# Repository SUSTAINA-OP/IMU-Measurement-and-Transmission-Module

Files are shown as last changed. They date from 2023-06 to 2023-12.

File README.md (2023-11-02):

<html lang="en">

<head>
    <meta charset="uft-8">
    <meta name="author" content="Masato Kubotera">
    <meta name="description" content="">
</head>

<body>
    <p><strong>This product is currently under development!</strong></p>
    <h1>IMU Measurement and Transmission Module</h1>
        <p>
            This product is a module enabling the <a href="https://github.com/SUSTAINA-OP/ICM-42688-P-Module">SUSTAINA-OP/ICM-42688-P-Module</a> (IMU module) to be connected to a USB or RS-485 I/F through a microcontroller.<br><br>
            The <a href="/firmware">firmware</a> for this product to be written to the microcontroller is a modification of the following library.
            <ul>
                <li><a href="https://github.com/finani/ICM42688">finani/ICM42688</a></li>
            </ul>
            (The firmware of this product currently supports only USB I/F connection.)
        </p>
    <h2>Features Rev. 1</h2>
        <p>
            <table>
                <tr>
                    <th>Top Surface of PCB</th>
                    <th>Bottom Surface of PCB</th>
                    <th>Assembled Electronic Components</th>
                </tr>
                <tr>
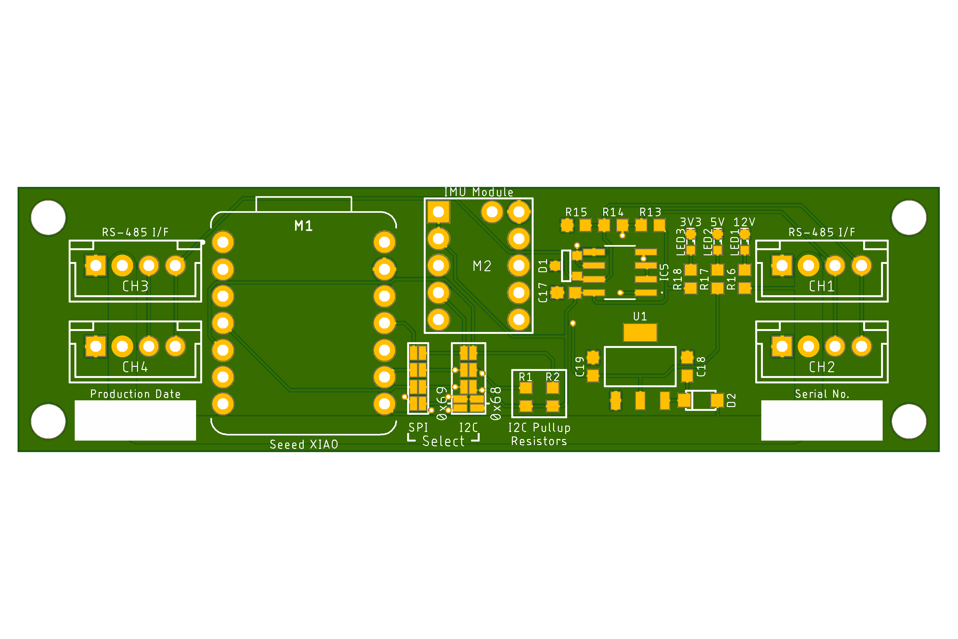
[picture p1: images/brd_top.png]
                    <td></td>
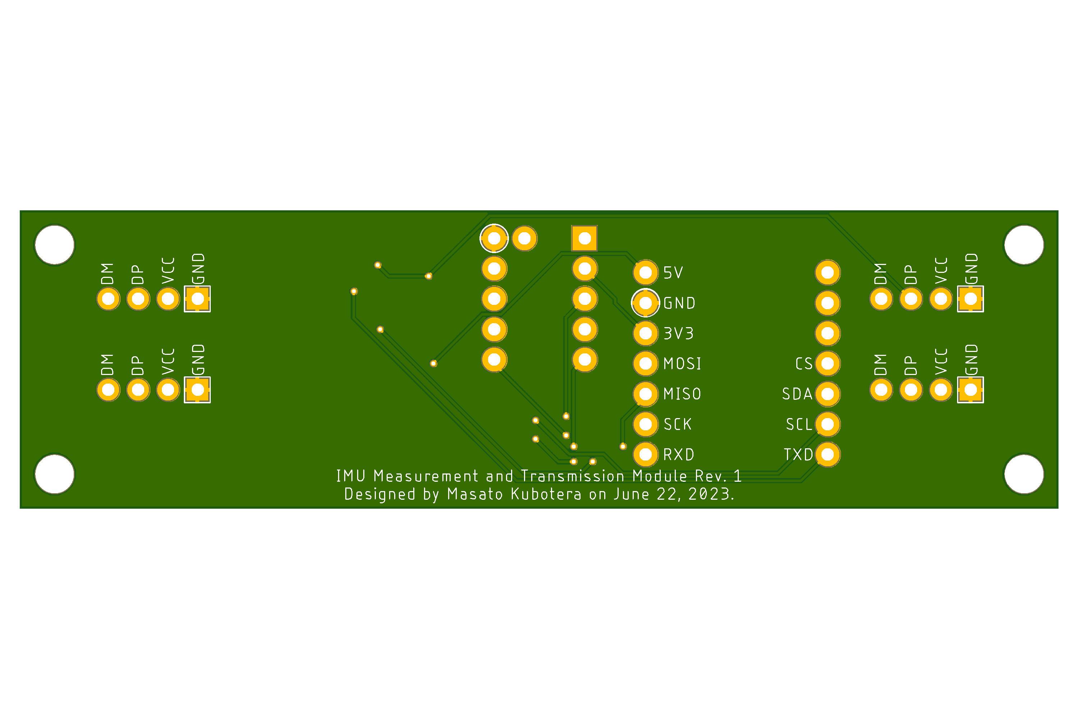
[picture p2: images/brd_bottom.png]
                    <td></td>
                    <td></td>
                </tr>
            </table>
        </p>
    <h3>PCB</h3>
        <p>
            <ul>
                <li>87mm x 25mm PCB layout</li>
            </ul>
        </p>
    <h2>Development Environments</h2>
    <p>
        This product is designed with the following software.
            <ul>
                <li><a href="https://www.autodesk.com/products/eagle/overview">Autodesk Eagle 9.6.2</a></li>
                <li><a href="https://www.arduino.cc/en/software">Arduino IDE 1.8.19</a></li>
            </ul>
    </p>
    <h2>Repository Contents</h2>
        <p>
            <dl>
                <dt><a href="/images">\images</a></dt>
                <dd>PCB preview images and capture of design screen</dd>
                <dt><a href="/libraries">\libraries</a></dt>
                <dd>Libraries used in Autodesk Eagle design</dd>
                <dt><a href="/pcb_order">\pcb_order</a> </dt>
                <dd>Gerber data and documentation for ordering PCB</dd>
                <dt><a href="/firmware">\firmware</a> </dt>
                <dd>Sample firmware to be written to the microcontroller board</dd>
                <dt><a href="/schematic.pdf">schematic.pdf</a></dt>
                <dd>Circuit diagram of this product</dd>
                <dt>*.brd</dt>
                <dd>Board wiring design file by Autodesk Eagle</dd>
                <dt>*.sch</dt>
                <dd>Circuit diagram design file by Autodesk Eagle</dd>
                <dt><a href="/.gitignore">.gitignore</a></dt>
                <dd>A file that tells Git not to track a particular file</dd>
                <dt><a href="/LICENSE">LICENSE</a></dt>
                <dd>License to use this product</dd>
            </dl>
        </p>
    <h2>Documentation</h2>
    <h3>Documentation</h3>
        <p>
            The following design errors have been identified in Rev. 1 of this product.
            <ul>
              <li>TXDEN of UART/RS-485 conversion IC is not wired to the microcontroller board</li>
                When used with USB I/F, there is no problem, but when used with RS-485 I/F, solder a jumper wire between TXDEN and the microcontroller as shown in the figure below.<br>
                
            </ul>
        </p>
    <h2>References</h2>
        
    <h2>Contact</h2>
        <p>
            If you have any questions, please contact the designer of this product, Masato Kubodera, by <a href="mailto:masato.kubotera@sustaina-op.com">e-mail</a>.<br>
            E-mail: <a href="mailto:masato.kubotera@sustaina-op.com">masato.kubotera@sustaina-op.com</a>
        </p>
    <h2>License Information</h2>
        <p>
            This product is open source. Please review the <a href="/LICENSE">LICENSE</a> for license information.<br>
            <br>
            This product by Masato Kubotera is licensed under a <a href="http://creativecommons.org/licenses/by-nc-sa/4.0/">Creative Commons Attribution-NonCommercial-ShareAlike 4.0 International License</a>.
        </p>
</body>
</html>

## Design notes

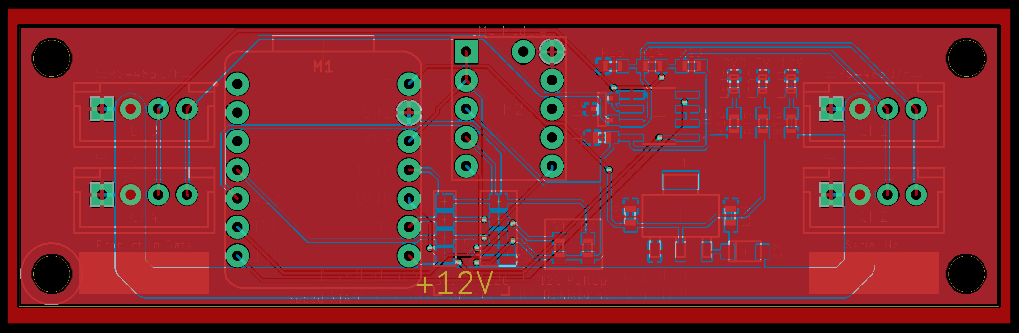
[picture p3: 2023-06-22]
images/brd.png

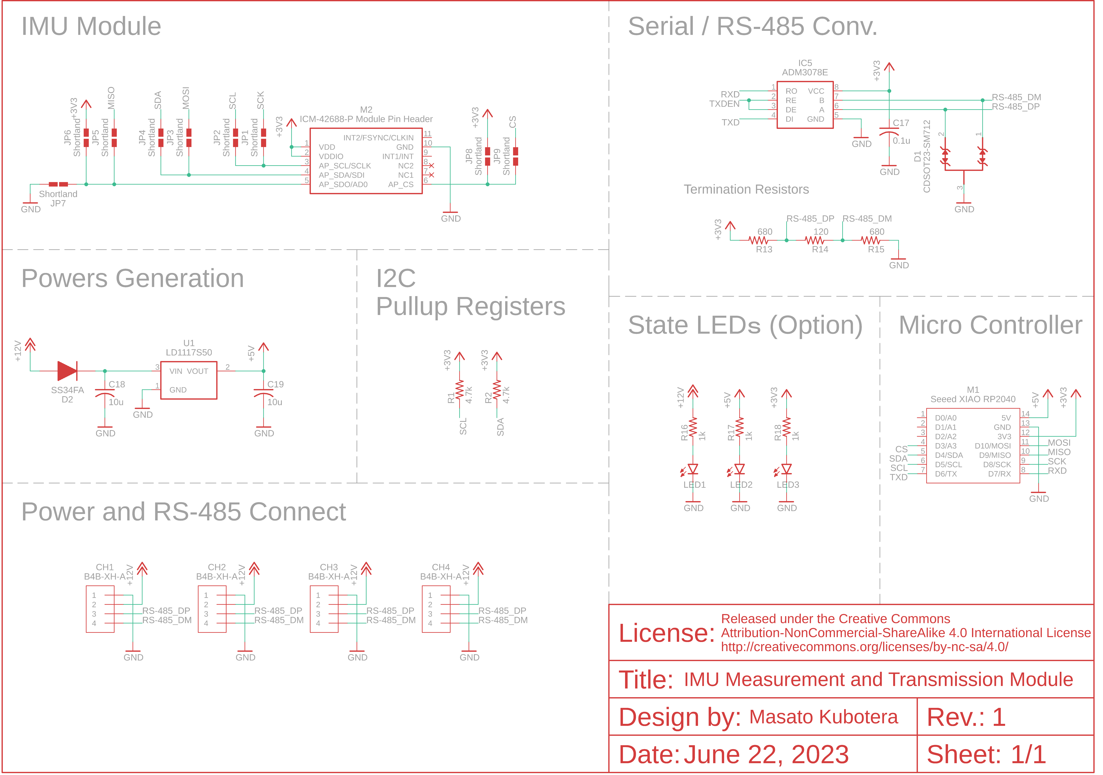
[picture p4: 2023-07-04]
images/sch.png

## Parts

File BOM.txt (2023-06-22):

Qty Value                        Device                       Package                      Parts                                       Description                
3                                LEDSML0603                   SML0603                      LED1, LED2, LED3                            LED                        
1   0.1u                         C-USC0603                    C0603                        C17                                         CAPACITOR, American symbol 
2   10u                          C-USC0603                    C0603                        C18, C19                                    CAPACITOR, American symbol 
1   120                          R-US_R0603                   R0603                        R14                                         RESISTOR, American symbol  
3   1k                           R-US_R0603                   R0603                        R16, R17, R18                               RESISTOR, American symbol  
2   4.7k                         R-US_R0603                   R0603                        R1, R2                                      RESISTOR, American symbol  
2   680                          R-US_R0603                   R0603                        R13, R15                                    RESISTOR, American symbol  
1   ADM3078E                     ADM3078E                     ADM3078E                     IC5                                                                    
4   B4B-XH-A                     B4B-XH-A                     B4B-XH-A                     CH1, CH2, CH3, CH4                                                     
1   CDSOT23-SM712                CDSOT23-SM712                SOT-23-3                     D1                                                                     
1   ICM-42688-P-MODULE-PINHEADER ICM-42688-P-MODULE-PINHEADER ICM-42688-P-MODULE-PINHEADER M2                                                                     
1   LD1117S50                    LD1117S50                    SOT-223                      U1                                                                     
1   SEEED_XIAO_RP2040_HOLE       SEEED_XIAO_RP2040_HOLE       SEEED_XIAO_HOLE              M1                                                                     
9   SHORTLAND                    SHORTLAND                    SHORTLAND                    JP1, JP2, JP3, JP4, JP5, JP6, JP7, JP8, JP9                            
1   SS34FA                       SS34FA                       SS34FA                       D2

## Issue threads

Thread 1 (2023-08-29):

ジャイロバイアスについて考えてみる

MasatoKubotera, 2023-08-29:
https://www.denshi.e.kaiyodai.ac.jp/wp-content/uploads/pdf/content1/2020komatsu.pdf

MasatoKubotera, 2023-08-29:
温度補償は，外気によっても左右されるし，デバイス温度（接続時間）によって変化する．

MasatoKubotera, 2023-09-03:
温度によるジャイロバイアスの値変化について検証

以下４回，ジャイロバイアスと温度を計測して変化を見てみる．
いずれも，姿勢は直立姿勢（IMUは水平）

1. 電源投下直後
2. 電源投下から５分後（競技開始前）
3. 競技開始５分後
4. 競技開始１０分後

MasatoKubotera, 2023-09-03:
Tまたはtを送信することで，バイアス値と温度を返すやつ
https://github.com/SUSTAINA-OP/IMU-Measurement-and-Transmission-Module/commit/d03349ed49b2dd99f770acb1b575149ac3c89a1f

MasatoKubotera, 2023-09-03:
ターミナルからバイアス値，温度を取得するやつ
```.py
import serial
import time

ser = serial.Serial('/dev/ttyACM0', 115200, timeout=1)

try:
    ser.write(b't')

    start_time = time.time()
    while True:
        response = ser.readline().decode('utf-8').strip()
        if response:
            print("ICM-42688-P: ", response)
            break

        if time.time() - start_time > 10:
            print("timeout")
            break

except KeyboardInterrupt:
    print("finish\n")

finally:
    ser.close()
```

MasatoKubotera, 2023-09-13:
検証結果
https://github.com/citbrains/sustaina-log/issues/24#issuecomment-1715408113

Closed 2023-11-05.

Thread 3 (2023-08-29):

FlashStorageEEPROMが使いにくい問題

MasatoKubotera, 2023-08-29:
ジャイロバイアスを保持するために，EEPROMが必要となる．

現状，マイコンボードとして使用している[Seeeduino XIAO](https://akizukidenshi.com/catalog/g/gM-15178/ )には，EEPROMが実装されていないため，[FlashStorage](https://www.arduino.cc/reference/en/libraries/flashstorage/) ：不揮発性フラッシュ メモリを使用してユーザー データを保存および取得している．

この特有の仕様として，プログラムを書き込むとリセットされてしまうため，バイアス値などの保存に適していない．

MasatoKubotera, 2023-11-02:
外部EEPROMorEEPROMを搭載しているArduinoを積むことが容易な解決策になるかもしれない．
両者ともにPCBを新たに作る必要がある．

EEPROM候補
I2C シリアルEEPROM AT24C32E
https://akizukidenshi.com/catalog/g/gI-15715/
https://www.arduino.cc/reference/en/libraries/at24cxx/

MasatoKubotera, 2023-11-08:
Flash Storageにfoalt型変数値を保存した後，値取り出すと，保存した値と異なることが判明．

ジャイロバイアスを更新（推定されたジャイロバイアスを返す）
```
<----
command  :  B0
crc      :  28486
txbuf    :  ['FE', 'FE', 'B0', '46', '6F']
<----
---->
rxbuf    :  ['FE', 'FE', 'B0', '13', '00', '40', '51', 'B0', 'BF', '80', 'D7', '35', 'BF', '00', 'D2', 'C2', 'BE', '6E', '82']
command  :  B0
length   :  19
error    :  00
crc      : 33390
check crc: True
data     : [-1.3774795532226562, -0.7103195190429688, -0.3805084228515625]
---->
```

Flash Storageに保存されているバイアスを取り出す
```
<----
command  :  A6
crc      :  7601
txbuf    :  ['FE', 'FE', 'A6', 'B1', '1D']
<----
---->
rxbuf    :  ['FE', 'FE', 'A6', '13', '00', 'C0', '06', 'B0', 'BF', '00', '20', '35', 'BF', '00', '09', 'C2', 'BE', '43', 'D6']
command  :  A6
length   :  19
error    :  00
crc      : 54851
check crc: True
data     : [-1.3752059936523438, -0.70751953125, -0.37897491455078125]
---->
```

diff
0xB0 rxbuf    :  ['FE', 'FE', 'B0', '13', '00', '40', '51', 'B0', 'BF', '80', 'D7', '35', 'BF', '00', 'D2', 'C2', 'BE', '6E', '82']
0xA6 rxbuf    :  ['FE', 'FE', 'A6', '13', '00', 'C0', '06', 'B0', 'BF', '00', '20', '35', 'BF', '00', '09', 'C2', 'BE', '43', 'D6']

---

適応ファームウェア：https://github.com/SUSTAINA-OP/IMU-Measurement-and-Transmission-Module/tree/fdd1aa3bdd7b03befb92f92156f7a4745ce25113

MasatoKubotera, 2023-11-10:
コマンド返答を以下に書き換え，どの程度ズレが出ているのか，タイミング確認した．

ズレは以下の通り
| 推定値 | 再起動前 読み込み値 | 再起動後 読み込み値 |
|--|--|--|
|-0.791778564453125, -0.211151123046875, 0.20139312744140625 | -0.791778564453125, -0.211151123046875, 0.20139312744140625 | -0.8403472900390625, -0.20917510986328125, 0.209930419921875 |
| -0.8111572265625, -0.2068939208984375, 0.1974029541015625 | -0.8111572265625, -0.2068939208984375, 0.1974029541015625 | -0.8143234252929688, -0.2071075439453125, 0.196990966796875 |
| -0.8130569458007812, -0.20777130126953125, 0.19886016845703125 | -0.8130569458007812, -0.20777130126953125, 0.19886016845703125 | -0.8178176879882812, -0.21080780029296875, 0.19875335693359375 |
| -0.8159637451171875, -0.210906982421875, 0.1997528076171875 | -0.8159637451171875, -0.210906982421875, 0.1997528076171875 | -0.8194046020507812, -0.21308135986328125, 0.2052154541015625 |
| -0.8130035400390625, -0.203948974609375, 0.19659423828125 |  -0.8130035400390625, -0.203948974609375, 0.19659423828125 | -0.8169174194335938, -0.2109222412109375, 0.1973419189453125 |

ズレが出ているタイミングは，以下参照

ジャイロバイアスを推定
⇓
推定値を書き込む
⇓
推定値を読み込む
⇓
Arduino Boardを再起動（電源は入れたまま）⇦多分このタイミング
⇓　
推定値を読み込む

このタイミングによって，書き込み／読み込みの関数自体が問題といことではく，
不揮発性フラッシュメモリーに書き込むこと自体が問題

```.ino
void processCommand(uint8_t command) {
  switch (command) {
    case storedBiasCommand:
      /**
            * @brief: reads gyro bias stored in non-volatile flash memory
            * @return: 3-axis gyro bias [dps] in non-volatile flash memory
            */

      transmitted_data.push_back(gyrB_x.read());
      transmitted_data.push_back(gyrB_y.read());
      transmitted_data.push_back(gyrB_z.read());
      break;

    case resetupBiasCommand:
      /**
            * @brief: estimates the gyro bias, adapt the estimated gyro bias, store it in non-volatile flash memory
            * @return: estimated 3-axis gyro bias [dps]
            */

      imu_status = IMU.calibrateGyro();

      //! store bias in non-volatile flash memory
      gyrB_x.write(IMU.getGyroBiasX());
      gyrB_y.write(IMU.getGyroBiasY());
      gyrB_z.write(IMU.getGyroBiasZ());

      transmitted_data.push_back(IMU.getGyroBiasX());
      transmitted_data.push_back(IMU.getGyroBiasY());
      transmitted_data.push_back(IMU.getGyroBiasZ());
      transmitted_data.push_back(gyrB_x.read());
      transmitted_data.push_back(gyrB_y.read());
      transmitted_data.push_back(gyrB_z.read());
      break;

    default:
      transmitted_error = commandErrorStatus;
  }
}
```
以下，コマンド送受信歴．
```
masato@xps-9700:~/IMU-Measurement-and-Transmission-Module/samples$ python3 imu_master_for_once.py
<----
command  :  B0
crc      :  28486
txbuf    :  ['FE', 'FE', 'B0', '46', '6F']
<----
---->
rxbuf    :  ['FE', 'FE', 'B0', '1F', '00', '00', 'B2', '4A', 'BF', '00', '38', '58', 'BE', '00', '3A', '4E', '3E', '00', 'B2', '4A', 'BF', '00', '38', '58', 'BE', '00', '3A', '4E', '3E', 'F0', '60']
command  :  B0
length   :  31
error    :  00
crc      : 24816
check crc: True
data     : [-0.791778564453125, -0.211151123046875, 0.20139312744140625, -0.791778564453125, -0.211151123046875, 0.20139312744140625]
---->
tx       :  2
rx       :  1
crc error:  0.0 %

masato@xps-9700:~/IMU-Measurement-and-Transmission-Module/samples$ python3 imu_master_for_once.py
<----
command  :  A5
crc      :  11730
txbuf    :  ['FE', 'FE', 'A5', 'D2', '2D']
<----
---->
rxbuf    :  ['FE', 'FE', 'A5', '13', '00', '00', '21', '57', 'BF', '00', '32', '56', 'BE', '00', 'F8', '56', '3E', '6D', '8F']
command  :  A5
length   :  19
error    :  00
crc      : 36717
check crc: True
data     : [-0.8403472900390625, -0.20917510986328125, 0.209930419921875]
---->
tx       :  1
rx       :  1
crc error:  0.0 %
```

```
masato@xps-9700:~/IMU-Measurement-and-Transmission-Module/samples$ python3 imu_master_for_once.py
<----
command  :  B0
crc      :  28486
txbuf    :  ['FE', 'FE', 'B0', '46', '6F']
<----
---->
rxbuf    :  ['FE', 'FE', 'B0', '1F', '00', '00', 'A8', '4F', 'BF', '00', 'DC', '53', 'BE', '00', '24', '4A', '3E', '00', 'A8', '4F', 'BF', '00', 'DC', '53', 'BE', '00', '24', '4A', '3E', '67', '9B']
command  :  B0
length   :  31
error    :  00
crc      : 39783
check crc: True
data     : [-0.8111572265625, -0.2068939208984375, 0.1974029541015625, -0.8111572265625, -0.2068939208984375, 0.1974029541015625]
---->
tx       :  2
rx       :  1
crc error:  0.0 %

masato@xps-9700:~/IMU-Measurement-and-Transmission-Module/samples$ python3 imu_master_for_once.py
<----
command  :  A5
crc      :  11730
txbuf    :  ['FE', 'FE', 'A5', 'D2', '2D']
<----
---->
rxbuf    :  ['FE', 'FE', 'A5', '13', '00', '80', '77', '50', 'BF', '00', '14', '54', 'BE', '00', 'B8', '49', '3E', '59', '93']
command  :  A5
length   :  19
error    :  00
crc      : 37721
check crc: True
data     : [-0.8143234252929688, -0.2071075439453125, 0.196990966796875]
---->
tx       :  1
rx       :  1
crc error:  0.0 %
```

```
masato@xps-9700:~/IMU-Measurement-and-Transmission-Module/samples$ python3 imu_master_for_once.py
<----
command  :  B0
crc      :  28486
txbuf    :  ['FE', 'FE', 'B0', '46', '6F']
<----
---->
rxbuf    :  ['FE', 'FE', 'B0', '1F', '00', '80', '24', '50', 'BF', '00', 'C2', '54', 'BE', '00', 'A2', '4B', '3E', '80', '24', '50', 'BF', '00', 'C2', '54', 'BE', '00', 'A2', '4B', '3E', 'E4', '6C']
command  :  B0
length   :  31
error    :  00
crc      : 27876
check crc: True
data     : [-0.8130569458007812, -0.20777130126953125, 0.19886016845703125, -0.8130569458007812, -0.20777130126953125, 0.19886016845703125]
---->
tx       :  2
rx       :  1
crc error:  0.0 %

masato@xps-9700:~/IMU-Measurement-and-Transmission-Module/samples$ python3 imu_master_for_once.py
<----
command  :  A5
crc      :  11730
txbuf    :  ['FE', 'FE', 'A5', 'D2', '2D']
<----
---->
rxbuf    :  ['FE', 'FE', 'A5', '13', '00', '80', '5C', '51', 'BF', '00', 'DE', '57', 'BE', '00', '86', '4B', '3E', '6F', '7F']
command  :  A5
length   :  19
error    :  00
crc      : 32623
check crc: True
data     : [-0.8178176879882812, -0.21080780029296875, 0.19875335693359375]
---->
tx       :  1
rx       :  1
crc error:  0.0 %
```

```
masato@xps-9700:~/IMU-Measurement-and-Transmission-Module/samples$ python3 imu_master_for_once.py
<----
command  :  B0
crc      :  28486
txbuf    :  ['FE', 'FE', 'B0', '46', '6F']
<----
---->
rxbuf    :  ['FE', 'FE', 'B0', '1F', '00', '00', 'E3', '50', 'BF', '00', 'F8', '57', 'BE', '00', '8C', '4C', '3E', '00', 'E3', '50', 'BF', '00', 'F8', '57', 'BE', '00', '8C', '4C', '3E', 'FF', '69']
command  :  B0
length   :  31
error    :  00
crc      : 27135
check crc: True
data     : [-0.8159637451171875, -0.210906982421875, 0.1997528076171875, -0.8159637451171875, -0.210906982421875, 0.1997528076171875]
---->
tx       :  2
rx       :  1
crc error:  0.0 %

masato@xps-9700:~/IMU-Measurement-and-Transmission-Module/samples$ python3 imu_master_for_once.py
<----
command  :  A5
crc      :  11730
txbuf    :  ['FE', 'FE', 'A5', 'D2', '2D']
<----
---->
rxbuf    :  ['FE', 'FE', 'A5', '13', '00', '80', 'C4', '51', 'BF', '00', '32', '5A', 'BE', '00', '24', '52', '3E', 'AA', '6F']
command  :  A5
length   :  19
error    :  00
crc      : 28586
check crc: True
data     : [-0.8194046020507812, -0.21308135986328125, 0.2052154541015625]
---->
tx       :  1
rx       :  1
crc error:  0.0 %
```

```
masato@xps-9700:~/IMU-Measurement-and-Transmission-Module/samples$ python3 imu_master_for_once.py
<----
command  :  B0
crc      :  28486
txbuf    :  ['FE', 'FE', 'B0', '46', '6F']
<----
---->
rxbuf    :  ['FE', 'FE', 'B0', '1F', '00', '00', '21', '50', 'BF', '00', 'D8', '50', 'BE', '00', '50', '49', '3E', '00', '21', '50', 'BF', '00', 'D8', '50', 'BE', '00', '50', '49', '3E', '16', '4F']
command  :  B0
length   :  31
error    :  00
crc      : 20246
check crc: True
data     : [-0.8130035400390625, -0.203948974609375, 0.19659423828125, -0.8130035400390625, -0.203948974609375, 0.19659423828125]
---->
tx       :  2
rx       :  1
crc error:  0.0 %

masato@xps-9700:~/IMU-Measurement-and-Transmission-Module/samples$ python3 imu_master_for_once.py
<----
command  :  A5
crc      :  11730
txbuf    :  ['FE', 'FE', 'A5', 'D2', '2D']
<----
---->
rxbuf    :  ['FE', 'FE', 'A5', '13', '00', '80', '21', '51', 'BF', '00', 'FC', '57', 'BE', '00', '14', '4A', '3E', '00', 'C4']
command  :  A5
length   :  19
error    :  00
crc      : 50176
check crc: True
data     : [-0.8169174194335938, -0.2109222412109375, 0.1973419189453125]
---->
tx       :  1
rx       :  1
crc error:  0.0 %
```

MasatoKubotera, 2023-11-19:
マスターからスレーブへの値転送に対応．
また，ジャイロバイアスを任意の値に設定できるコマンドを追加．

これにより，Flash Storageに依存せずにバイアスを設定できるようになった．

この機能を使う場合は，あくまでもFlashStorageの値を信用したくないとき，任意のときに適応するバイアスを変更できるものである．

そのため，信用できる任意のバイアスを使用したい場合は，
ソフトウェア的に，USBポートを開く度に任意のバイアスを設定する必要がある．

推定されたバイアスを取り出すだけのコマンドも用意がされている．

- https://github.com/SUSTAINA-OP/IMU-Measurement-and-Transmission-Module/issues/7#issuecomment-1808084797

- https://github.com/SUSTAINA-OP/IMU-Measurement-and-Transmission-Module/tree/7ed6a95d300e31a34338bd3048b8437b1193f882

MasatoKubotera, 2023-11-19:
上記の解決策は，EEPROMが実装されていないXAIOに対するアプローチなので，次期基板を設計するときには，EEPROMが実装されているArduinoボードまたは外部にEEPROMを実装し，マスター側にバイアスを保管させない仕様にする必要がある．

Closed 2023-11-19.

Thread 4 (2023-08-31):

内部状態のインジケータを実装する

MasatoKubotera, 2023-08-31:

MasatoKubotera, 2023-11-19:
エラー検出時にXIAOに実装されている拡張LEDを転倒させるようにした．
https://github.com/SUSTAINA-OP/IMU-Measurement-and-Transmission-Module/tree/95985650fc7721d48f4c3546cd5f5780fa5160b7

XIAOには，LEDが以下の4つ実装されている．
- TX LED (青)
- RX LED (青)
- 拡張LED (橙)
- 電源LED (緑)
https://files.seeedstudio.com/wiki/Seeeduino-XIAO/res/Seeeduino-XIAO-v1.0-SCH-191112.pdf

Tx/Rx LEDは，USB Serialにおいて通信しているときに点灯する．
※ポートが開かれていないときには点灯しない．

これらのLEDは密集して実装されているため，遠くからの可視は難しい．
そのため，次期基板で別途LEDを実装できればよいと考えている．

（この時はエラービット事にLEDを実装するか検討中）

Closed 2023-11-19.

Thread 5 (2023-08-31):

USB通信とIMU処理をマルチスレッドにする

MasatoKubotera, 2023-08-31:

MasatoKubotera, 2023-08-31:
https://smtengkapi.com/engineer-seeeduino-xiao-freertos

MasatoKubotera, 2023-09-29:
1. FreeRTOSライブラリを使用する方法
2. マルチコアのマイコンボードを使用する方法
  [Seeed XIAO RP2040](https://www.seeedstudio.com/XIAO-RP2040-v1-0-p-5026.html)
  Dual-core ARM Cortex M0+ processor, flexible clock running up to 133 MHz
  ➤[FlashStorageライブラリ](https://www.arduino.cc/reference/en/libraries/flashstorage/)がATSAMD21 and ATSAMD51しか対応していない．

MasatoKubotera, 2023-11-19:
https://ameblo.jp/pta55/entry-12798012318.html

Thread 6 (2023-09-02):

温度を取得する

MasatoKubotera, 2023-09-02:
ジャイロバイアスは，温度によって変化する．これらの検証のために，シングルボードコンピュータからIMUセンサーモジュール内部の温度を取得できるようにする．

MasatoKubotera, 2023-09-02:
送信文字列の最後尾に温度（摂氏）の値（float 4byte分）を追加しました．

https://github.com/SUSTAINA-OP/IMU-Measurement-and-Transmission-Module/commit/dd4fc939e2336629da8575de5296dd4cbccc6b92

MasatoKubotera, 2023-09-13:
以下でmasterにmergeされたのでファームウェアを更新する．
https://github.com/citbrains/citbrains_humanoid/pull/2035

- [ ] No. 181
- [ ] No. 182
- [ ] No. 183
- [ ] No. 184
- [ ] No. 185
- [ ] No. 186

Closed 2023-11-08.

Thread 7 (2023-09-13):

接続確認モードの追加

MasatoKubotera, 2023-09-13:

MasatoKubotera, 2023-09-15:
バージョンの応答の方が良いかも

MasatoKubotera, 2023-10-19:
コマンド体系（データ構造・フォーマット）

SoMからの送信フォーマット

| byte | item | contents |
| --- | --- | --- |
| 1 | header | 0xFE |
| 1 | header | 0xFE |
| 1 | packet length | Length from header to CRC16 |
| 1 | command | - |
| 2 | CRC16-XMODEM | CRC16-XMODEM from header to command |

IMUからの応答フォーマット

| byte | item | contents |
| --- | --- | --- |
| 1 | header | 0xFE |
| 1 | header | 0xFE |
| 1 | packet length | Length from header to CRC16 |
| 1 | command | - |
| 1 | status | - |
| n | data | - |
| 2 | CRC16-XMODEM | CRC16-XMODEM from header to command |

参考：
PMX https://www.kondokagaku.jp/wp_mn/archives/1144#i-16
DYNAMIXEL Communiation Protocol 2.0 https://www.besttechnology.co.jp/modules/knowledge/?DYNAMIXEL%20Communiation%20Protocol%202.0#f7c5cc11

MasatoKubotera, 2023-10-19:
コマンド
- 値取得：加速度・ジャイロ・温度
  - 【応答】加速度（float値4バイト×3軸），ジャイロ（float値4バイト×3軸），温度（float値4バイト）
- 値取得：加速度
  - 【応答】加速度（float値4バイト×3軸）
- 値取得：ジャイロ
  - 【応答】ジャイロ（float値4バイト×3軸）
- 値取得：温度
  - 【応答】ジャイロ（float値4バイト×3軸）
- 値取得：ジャイロバイアス
  - 【応答】ジャイロバイアス（float値4バイト×3軸）
- 値設定：ジャイロバイアス
  ※値設定を開始するコマンド．値自体をSoMから送信する訳ではない．
- IMU初期化

MasatoKubotera, 2023-10-29:
| command | type | response | processing |
| --- | --- | --- | --- |
| 0xa0 | read | acceleration (x, y, z), gyro (x, y, z), temperature | |
| 0xa1 | read | acceleration (x, y, z) | |
| 0xa2 | read | gyro (x, y, z) | |
| 0xa3 | read | temperature | |
| 0xa4 | read | gyro bias (x, y, z) | |
| 0xb0 | setting | - | gyro bias (x, y, z) setting |

MasatoKubotera, 2023-11-05:
CRC16の計算

KONDO PMXシリーズに準拠
https://kondo-robot.com/faq/pmx-library-for-python

MasatoKubotera, 2023-11-06:
メモ：シングルボードコンピュータ側から指定したジャイロバイアス値を適応し使用のみ，およびArduino側のストレージに保存ができるようにする．

※常用コマンドではなく，完全なオプションとして使用することが前提

MasatoKubotera, 2023-11-08:
検証バージョンのファームウェアをリリースしました．

https://github.com/SUSTAINA-OP/IMU-Measurement-and-Transmission-Module/tree/fdd1aa3bdd7b03befb92f92156f7a4745ce25113

MasatoKubotera, 2023-11-08:
@AD58-3104
マスタースレーブの方で，IMUモジュールと接続するときに，ファームウェアバージョンの確認とバイアスオフセットが0ではないことを確認してください．

MasatoKubotera, 2023-11-08:
SUSTAINA-OP 18xに対応したので，ファームウェアをｍasterに統合，ロボットに反映する．

- [ ] 181
- [ ] 182
- [ ] 183
- [ ] 184
- [ ] 185
- [ ] 186

MasatoKubotera, 2023-11-08:
現状のコマンドおよびパケット構成

## 送信（マスタ→スレーブ）

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

0xA0: 加速度，ジャイロ，温度取得
0xA1: 加速度取得
0xA2: ジャイロ取得
0xA3: 温度取得
0xA4: 新規推定バイアス取得
0xA5: 保存済みバイアス取得
0xA6: 適応済みバイアス取得

0xB0: ジャイロバイアス更新

0xC0: ファームウェアバージョン取得

## 応答（スレーブ→マスタ）

0xA* or 0xB*
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

0xA0: データ（加速度x，加速度y，加速度z，ジャイロx，ジャイロy，ジャイロz，温度）
0xA1: データ（加速度x，加速度y，加速度z）
0xA2: データ（ジャイロx，ジャイロy，ジャイロz）
0xA3: データ（温度）
0xA4: データ（ジャイロバイアスx，ジャイロバイアスxy，ジャイロバイアスxz）
0xA5: データ（ジャイロバイアスxx，ジャイロバイアスxy，ジャイロバイアスxz）
0xA6: データ（ジャイロバイアスxx，ジャイロバイアスxy，ジャイロバイアスxz）

0xB0: データ（ジャイロバイアスxx，ジャイロバイアスxy，ジャイロバイアスxz）

0xC*
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
0xC0: データ（ファームウェアバージョン）

MasatoKubotera, 2023-11-13:
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

MasatoKubotera, 2023-11-27:
シリアルポートを開くとArduino側で初期化処理が入る．
そのため，Arduno内部でも最低1500 msの処理時間が発生する．

MasatoKubotera, 2023-12-13:
ファームウェア Ver. 1をリリースしました．
https://github.com/SUSTAINA-OP/IMU-Measurement-and-Transmission-Module/releases/tag/ver.1

バイアスは，ArduinoボードのFlashStorageに書き込む方法とコンピュータボードに保管されたバイアスをArduinoボードに送信し使用する方法がある．

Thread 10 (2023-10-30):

ICMとArduinoの通信状態が取得できない

MasatoKubotera, 2023-10-30:
ICM42688から最新のデータを読み取り，バッファに保存に保存する際，ICMとArduinoが通信できない状態でもエラー（return < 0）とならなく，通信状態が取得できていない．

https://github.com/SUSTAINA-OP/IMU-Measurement-and-Transmission-Module/blob/3bd0b7465cd74c2477f245b46132e8cdf462dd83/firmware/src/ICM42688.cpp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

MasatoKubotera, 2023-10-30:
IMUモジュールを抜いた状態で，getAGT()を叩いた時の戻り値は1．

この時に取得した，加速度（ｘ，ｙ，ｚ），ジャイロ（ｘ，ｙ，ｚ），温度は以下のようになった．
[-0.000244140625, -0.000244140625, -0.000244140625, -0.030517578125, -0.030517578125, -0.030517578125, 24.99245262145996]

MasatoKubotera, 2023-10-30:
readRegistersのところにSPI接続の場合，return < 0とは仕様的にならない．

https://github.com/SUSTAINA-OP/IMU-Measurement-and-Transmission-Module/blob/3bd0b7465cd74c2477f245b46132e8cdf462dd83/firmware/src/ICM42688.cpp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

MasatoKubotera, 2023-10-30:
I２C接続において，
IMUモジュールを抜いた状態で，getAGT()を叩いた時の戻り値は-1となった．

この時に取得した，加速度（ｘ，ｙ，ｚ），ジャイロ（ｘ，ｙ，ｚ），温度は以下のようになった．
[0.0, 0.0, 0.0, 0.0, 0.0, 0.0, 0.0]

hiroki-0001, 2023-11-02:
こちら調査しましたが、Arduino の I2C通信にはデータの送受信を行う前にデータの送受信回数(ICM42688の場合は加速度3 + ジャイロ3 + 温度1 で合計7)があっているかどうか確認する関数が存在します。`_i2c->requestFrom(_address, count)`

これを用いることでI2C通信の場合は通信中にデバイスとの接続不良が起こっても、即座に検知し、errorを吐き出すことができています。

しかし、SPI通信の場合はそういった関数がArduinoのライブラリに実装されていません。
https://github.com/arduino/ArduinoCore-samd/blob/master/libraries/SPI/SPI.cpp

公式ライブラリを改造するという手法を用いればいけなくもなさそうですがめんどくさそうです。
(以下の関数の一部を変更すればいけるかも？)
https://github.com/arduino/ArduinoCore-samd/blob/84c09b3265e2a8b548a29b141f0c9281b1baf154/cores/arduino/SERCOM.cpp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

またSPI通信で接続のエラー検知をする場合は前述した公式ライブラリの改造以外にも、手段はあります。
それは、ICM42688のSPI通信のread/write時に一番最初に行う通信の受信値を見る方法です。

[ICM42688のデータシート](https://product.tdk.com/system/files/dam/doc/product/sensor/mortion-inertial/imu/data_sheet/ds-000347-icm-42688-p-v1.6.pdf)のp.53にspi通信のコミュニケーションについて記載されてあります。

具体的な実装方法として考えているのは、毎回spi通信のデータを読み取るの際(read処理)にはArduinoのSPI.hの`transfer()`関数を用いて通信を行いますが、一番はじめに行う`transfer()`の返り値を確認するということです。この返り値はIMUの取得したセンサ値のように変動する値ではなく、おそらく固定の値だと考えられます。(データの送受信を行う最初の合図のような通信のため)

ただ厄介なのが、通信エラーの時の返り値の定義がどこのドキュメントを見てもわからず、どのような値のときは通信エラーだということがまだわかっていません。(おそらく0以外の値だとは考えられるが・・・)

これらの点から、今回の問題を解決する最短手順はI2C通信を使用することだと考えています。

MasatoKubotera, 2023-11-02:
今後の対応

>これらの点から、今回の問題を解決する最短手順はI2C通信を使用することだと考えています。

1. SPIとI2Cにおける ICM <-> Arduino間の通信速度の計測
シングルボードコンピュータが200Hzで値欲求してくるので十分な応答速度であるか検証
2. PCBにプルアップ抵抗を実装する必要があるかを検討
3.現状のPCBをSPIからI2C仕様に変更できるかの検討

MasatoKubotera, 2023-11-04:
IMUとマイコンのSPI通信でもWho Am Iを利用することで状態を確認することができる．
接続されていない場合，if(whoAmI() != WHO_AM_I)がfalseとなる．

https://github.com/SUSTAINA-OP/IMU-Measurement-and-Transmission-Module/blob/3bd0b7465cd74c2477f245b46132e8cdf462dd83/firmware/src/ICM42688.cpp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

https://github.com/SUSTAINA-OP/IMU-Measurement-and-Transmission-Module/blob/3bd0b7465cd74c2477f245b46132e8cdf462dd83/firmware/src/ICM42688.cpp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

この検証にかかる処理時間は，以下の関数を新たに設立して，**36.58 us**となった．
```.cpp
bool ICM42688::getWhoAmI() {
  // check the WHO AM I byte
  if(whoAmI() != WHO_AM_I) {
    return false;
  }
  return true;
}
```

参考値として，getAGT()の処理時間は，**138.236 us**であった．

シングルボードコンピュータから200 Hzで値要求しても十分な応答速度であるため，SPI通信の状態検出（接続，未接続）判定は，WhoAmIが利用できる．

MasatoKubotera, 2023-11-19:
Who Am Iを毎ループ事に実行し，返答を確認することで接続状態を得ることができるようした．

毎ループ事の再接続
https://github.com/SUSTAINA-OP/IMU-Measurement-and-Transmission-Module/blob/a4f66178149d63f8f5228e6769e0eedebfebed6d/firmware/firmware.ino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

再接続後のエラー処理
https://github.com/SUSTAINA-OP/IMU-Measurement-and-Transmission-Module/blob/a4f66178149d63f8f5228e6769e0eedebfebed6d/firmware/firmware.ino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

※Who Am Iでのエラー検出目的は，Begin関数実行時には接続されていて，その後通信が途絶えたことを検出するため．Begin関数では，内部にWho Am Iが実装されており，通信できない場合はBegin関数でエラーを返す．

追加したWho Am I関数
https://github.com/SUSTAINA-OP/IMU-Measurement-and-Transmission-Module/blob/a4f66178149d63f8f5228e6769e0eedebfebed6d/firmware/src/ICM42688/ICM42688.cpp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

問題点として，値取得と同時に通信状態を確認できないが，数百μの周期において無視できるレベルと判断する．

Closed 2023-11-19.

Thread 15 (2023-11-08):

ICM-42688-P 温度変化レポート

MasatoKubotera, 2023-11-08:
ICM-42688-Pでは，GYRO Offset Temp Stability (mdps/°C)が±5であることが判明．

https://product.tdk.com/system/files/dam/doc/product/sensor/mortion-inertial/imu/data_sheet/pb-000072-icm-42688-p.pdf

SUSTAINA-OP RoboCup2023 Editionでは，シングルボードコンピュータのヒートシンク／ファンの近くにIMUモジュールが設置されるため，温度変化が大きい．

温度変化がどの程度あるか検証してみる．

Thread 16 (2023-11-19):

ICM-42688-P 評価ボード「DK-42688-P」レビュー

MasatoKubotera, 2023-11-19:
DK-42688-P
- https://invensense.tdk.com/products/dk-42688-p/#documentation
- https://product.tdk.com/ja/search/sensor/mortion-inertial/imu/info?part_no=DK-42688-P
- https://www.mouser.jp/ProductDetail/410-DK-42688-P

DK-42688-P Product Brief
https://product.tdk.com/system/files/dam/doc/product/sensor/mortion-inertial/imu/data_sheet/dk-42688-p-product-brief.pdf

ICM-42688-P Datasheet
https://product.tdk.com/system/files/dam/doc/product/sensor/mortion-inertial/imu/data_sheet/ds-000347-icm-42688-p-v1.6.pdf

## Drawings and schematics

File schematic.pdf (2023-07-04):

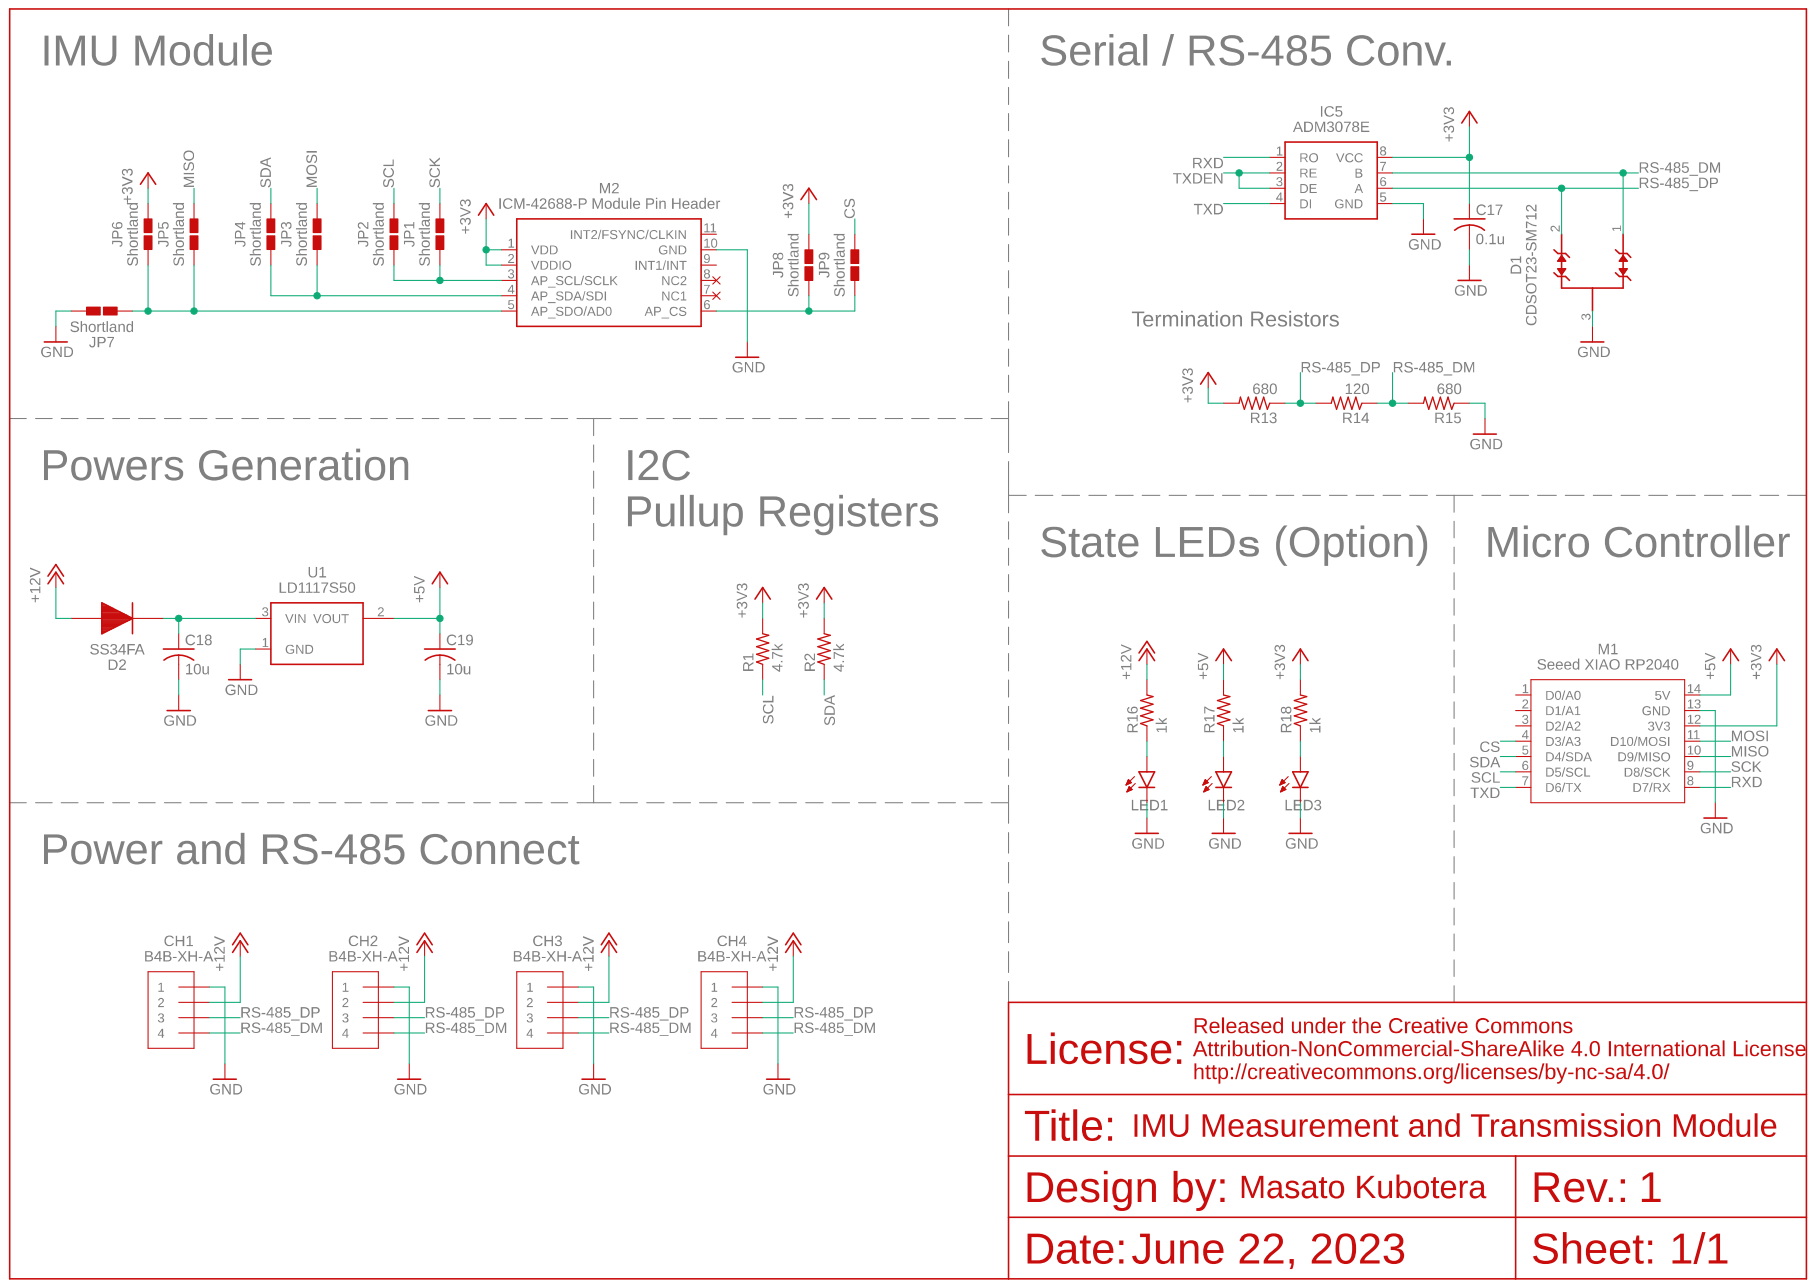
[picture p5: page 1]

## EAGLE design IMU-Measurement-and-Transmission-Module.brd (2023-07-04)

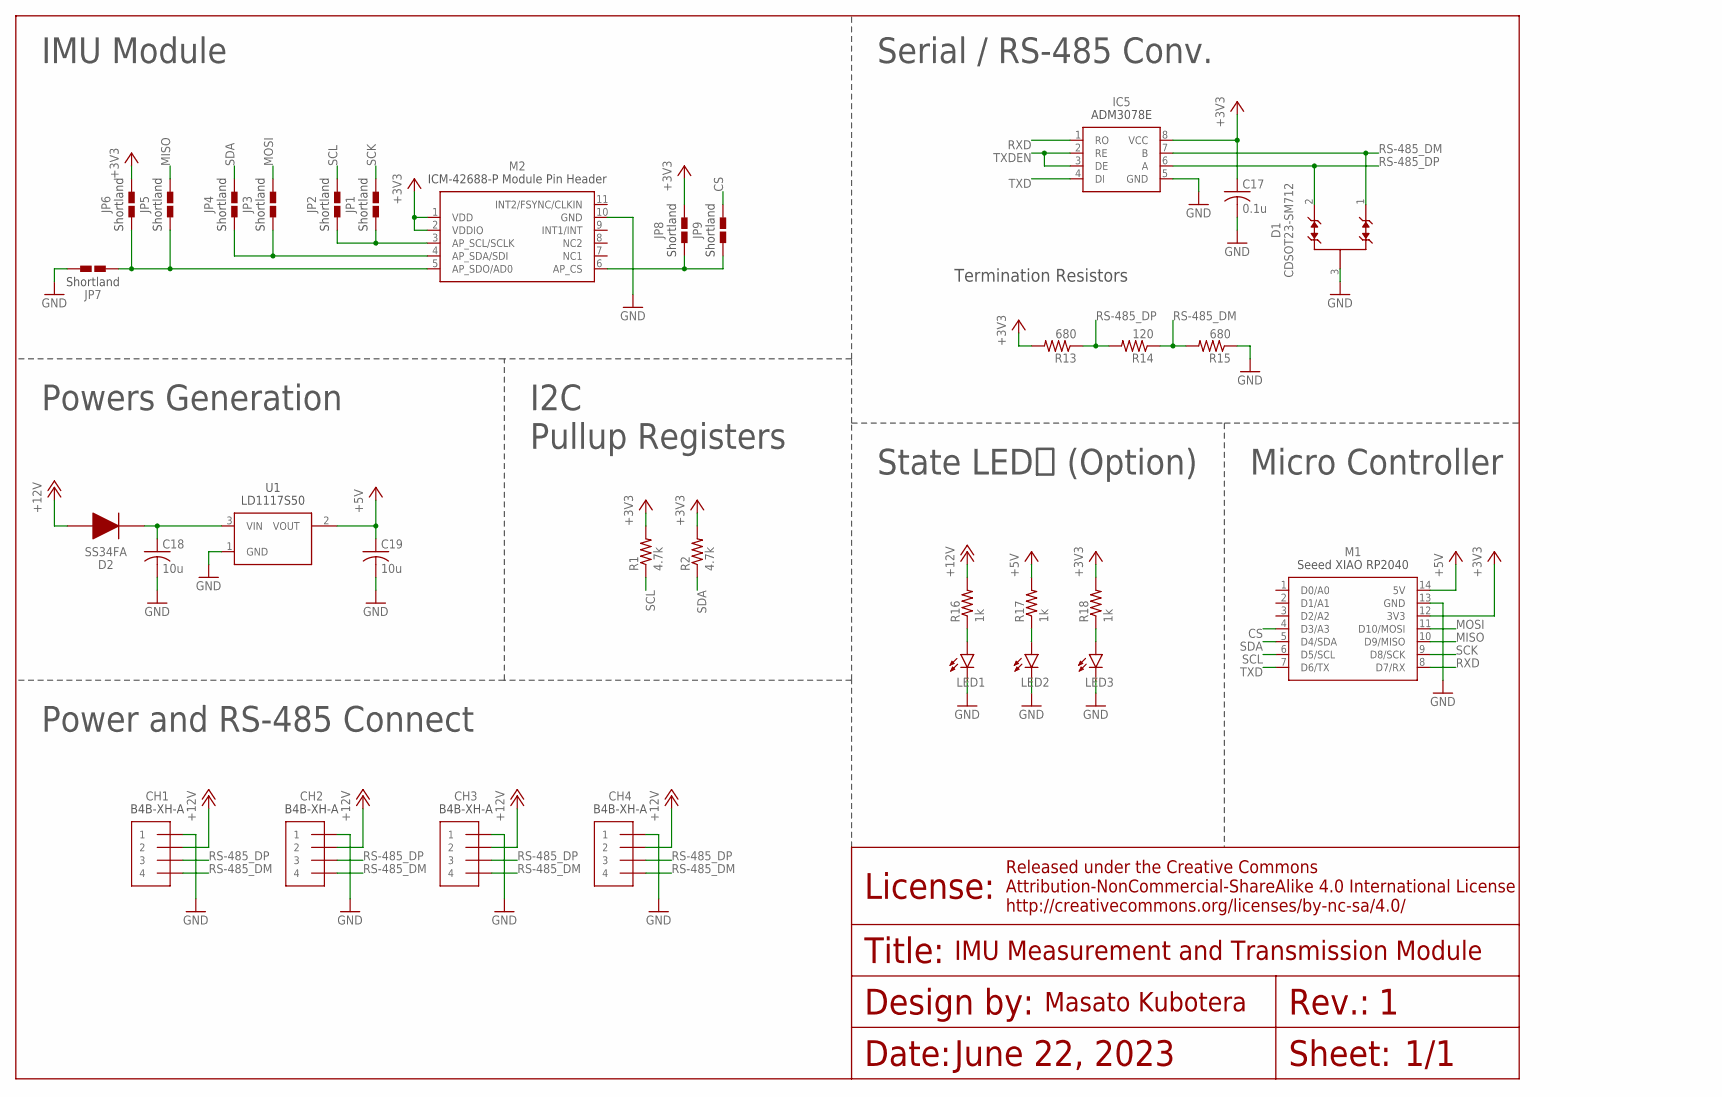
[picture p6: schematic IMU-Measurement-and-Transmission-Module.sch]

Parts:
C17: 0.1u; C0603
C18, C19: 10u; C0603
CH1, CH2, CH3, CH4: B4B-XH-A
D1: CDSOT23-SM712; SOT-23-3
D2: SS34FA
IC5: ADM3078E
JP1, JP2, JP3, JP4, JP5, JP6, JP7, JP8, JP9: SHORTLAND
LED1, LED2, LED3: LEDSML0603; SML0603
M1: SEEED_XIAO_RP2040_HOLE; SEEED_XIAO_HOLE
M2: ICM-42688-P-MODULE-PINHEADER
R1, R2: 4.7k; R0603
R13, R15: 680; R0603
R14: 120; R0603
R16, R17, R18: 1k; R0603
U1: LD1117S50; SOT-223

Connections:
3V3_LED: LED3.A, R18.1
5V_LED: LED2.A, R17.1
12V_LED: LED1.A, R16.1
+3V3: C17.1, IC5.8 (VCC), JP6.2, JP8.2, M1.12 (3V3), M2.1 (VDD), M2.2 (VDDIO), R1.2, R2.2, R13.2, R18.2
+5V: C19.1, M1.14 (5V), R17.2, U1.2 (VOUT)
+12V: CH1.2, CH2.2, CH3.2, CH4.2, D2.2, R16.2
AP_CS: JP8.1, JP9.1, M2.6 (AP_CS)
AP_SCL/SCLK: JP1.1, JP2.1, M2.3 (AP_SCL/SCLK)
AP_SDA/SDI: JP3.1, JP4.1, M2.4 (AP_SDA/SDI)
AP_SDO/ADO: JP5.1, JP6.1, JP7.1, M2.5 (AP_SDO/AD0)
CS: JP9.2, M1.4 (D3/A3)
GND: C17.2, C18.2, C19.2, CH1.1, CH2.1, CH3.1, CH4.1, D1.3, IC5.5 (GND), JP7.2, LED1.C, LED2.C, LED3.C, M1.13 (GND), M2.10 (GND), R15.1, U1.1 (GND)
MISO: JP5.2, M1.10 (D9/MISO)
MOSI: JP3.2, M1.11 (D10/MOSI)
RS-485_DM: CH1.4, CH2.4, CH3.4, CH4.4, D1.1, IC5.7 (B), R14.1, R15.2
RS-485_DP: CH1.3, CH2.3, CH3.3, CH4.3, D1.2, IC5.6 (A), R13.1, R14.2
RXD: IC5.1 (RO), M1.8 (D7/RX)
SCK: JP1.2, M1.9 (D8/SCK)
SCL: JP2.2, M1.6 (D5/SCL), R1.1
SDA: JP4.2, M1.5 (D4/SDA), R2.1
TXD: IC5.4 (DI), M1.7 (D6/TX)
TXDEN: IC5.2 (RE), IC5.3 (DE)
VIN: C18.1, D2.1, U1.3 (VIN)

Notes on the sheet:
Serial / RS-485 Conv.
Powers Generation
Micro Controller
State LEDｓ (Option)
Power and RS-485 Connect
1/1
June 22, 2023
IMU Measurement and Transmission Module
Termination Resistors
I2C Pullup Registers
IMU Module

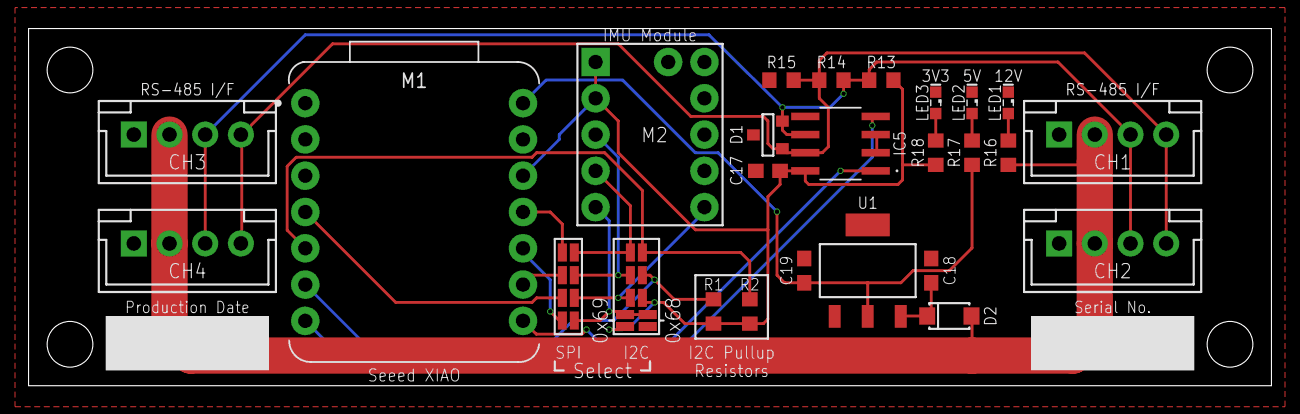
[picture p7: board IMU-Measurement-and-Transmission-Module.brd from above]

Board: 2 copper layers, 87.0 x 25.0 mm, 33 parts (0 on the bottom side), 23 nets.

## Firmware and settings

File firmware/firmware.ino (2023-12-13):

/**
  * Arduino Firmware for IMU Measurement and Transmission Module
  *
  * This firmware is intended to be written to an Arduino board mounted on the IMU Measurement and Transmission Module.
  * The Arduino board is assumed to be Seeeduino XIAO (CPU: SAMD21G18) made by Seed Studio.
  *
  * This firmware uses the FlashStorage library for SAMD21.
  * Therefore, this firmware is not compatible with another XAIO series board.
  *
  * In this firmware, communication with the IMU must be via SPI connection.
  * For I2C connection, change the arguments in the object definition of the class.
  */

#include "./src/ICM42688/ICM42688.h"
#include "./src/CRC16/CRC16.h"

#include <FlashStorage.h>
#include <vector>

/**
 * settings by users
 */
const uint8_t headerPacket[] = { 0xFE, 0xFE };
const uint8_t cs_pin = 3;
const uint32_t UsbSerial_baudrate = 115200;
const uint8_t firmwareVersion = 0x01;

//! command
//! commands to return the values: 0xA*
const uint8_t estimatedAccelGyroTempCommand = 0xA0;
const uint8_t estimatedAccelCommand = 0xA1;
const uint8_t estimatedGyroCommand = 0xA2;
const uint8_t estimatedTempCommand = 0xA3;
const uint8_t estimatedBiasCommand = 0xA4;
const uint8_t storedBiasCommand = 0xA5;
const uint8_t adaptedBiasCommand = 0xA6;

//! commands to change/return the values: 0xB*
const uint8_t setupBiasCommand = 0xB0;
const uint8_t replaceSpecifiedBiasCommand = 0xB1;
const uint8_t adaptedSpecifiedBiasCommand = 0xB2;

const uint8_t cheackFirmwareCommand = 0xD0;

//! error status
// const uint8_t rxPacket_errorStatus = 0b00000001;
const uint8_t crc_errorStatus = 0b00000010;
const uint8_t imuConnection_errorStatus = 0b00000100;
const uint8_t imuResponse_errorStatus = 0b00001000;
const uint8_t commandUnsupport_errorStatus = 0b00010000;
const uint8_t commandProcessing_errorStatus = 0b00100000;

/**
 * settings users do not need to change
 */

const size_t headerPacket_length = sizeof(headerPacket);
const size_t crc_length = sizeof(uint16_t);

//! rx packet: headder + command + length + data * n + crc
const size_t rxPacket_forward_length = headerPacket_length + 2;
const size_t rxPacket_min_length = rxPacket_forward_length + crc_length;

//! tx packet: headder + command + length + error + data * n + crc
const size_t txPacket_min_length = headerPacket_length + 3 + crc_length;

int16_t imuBeginStatus = 0;
int16_t imuResponseStatus = 0;

std::vector<float> rxFloatData;
std::vector<float> txFloatData;
std::vector<uint8_t> txByteData;

ICM42688 IMU(SPI, cs_pin);

CRC16 CRC;

//! settings for non-volatile flash memory
FlashStorage(gyrB_x, float);
FlashStorage(gyrB_y, float);
FlashStorage(gyrB_z, float);

void setup() {
  initializeSerial(UsbSerial_baudrate);
  initializeIMU();
}

void loop() {

  if (imuBeginStatus < 0 || !IMU.verifyWhoAmI()) {
    imuBeginStatus = IMU.begin();
  }

  if (Serial.available() >= rxPacket_min_length) {

    uint8_t rxPacket_forward[rxPacket_forward_length] = {};

    if (checkHeader(headerPacket, headerPacket_length, rxPacket_forward)) {

      for (int i = headerPacket_length; i < rxPacket_forward_length; i++) {
        rxPacket_forward[i] = Serial.read();
      }

      uint8_t rxCommand = rxPacket_forward[headerPacket_length];
      size_t rxPacket_length = rxPacket_forward[headerPacket_length + 1];

      uint8_t rxPacket[rxPacket_length] = {};

      for (int i = 0; i < rxPacket_length; i++) {
        if (i < rxPacket_forward_length) {
          rxPacket[i] = rxPacket_forward[i];
        } else {
          rxPacket[i] = Serial.read();
        }
      }

      uint8_t tx_errorStatus = 0b00000000;

      rxFloatData.clear();
      txFloatData.clear();
      txByteData.clear();

      size_t txFloatData_length = 0;
      size_t txByteData_length = 0;
      size_t txPacket_length = txPacket_min_length;

      if (CRC.checkCrc16(rxPacket, rxPacket_length)) {

        if (rxPacket_length > rxPacket_min_length) {

          size_t rxFloatData_length = rxPacket_length - rxPacket_min_length;

          uint8_t rxFloatData_bytes[rxFloatData_length] = {};
          for (int i = 0; i < rxFloatData_length; i++) {
            rxFloatData_bytes[i] = rxPacket[i + rxPacket_forward_length];
          }

          size_t rxFloatData_count = rxFloatData_length / sizeof(float);

          for (int i = 0; i < rxFloatData_count; i++) {
            float rxFloatData_float = 0;
            uint8_t* bytePtr = (uint8_t*)&rxFloatData_float;

            for (int j = 0; j < sizeof(float); j++) {
              bytePtr[j] = rxFloatData_bytes[i * sizeof(float) + j];
            }

            rxFloatData.push_back(rxFloatData_float);
          }
        }

        processCommand(rxCommand, &tx_errorStatus);

        if (!txFloatData.empty()) {
          txFloatData_length = txFloatData.size() * sizeof(float);
          txPacket_length += txFloatData_length;
        }

        if (!txByteData.empty()) {
          txByteData_length = txByteData.size() * sizeof(uint8_t);
          txPacket_length += txByteData_length;
        }
      } else {
        tx_errorStatus |= crc_errorStatus;
      }

      uint8_t txPacket[txPacket_length] = {};
      size_t packetIndex = 0;

      memcpy(txPacket, headerPacket, headerPacket_length);
      packetIndex += headerPacket_length;

      txPacket[packetIndex++] = rxCommand;
      txPacket[packetIndex++] = (uint8_t)txPacket_length;
      txPacket[packetIndex++] = tx_errorStatus;

      if (!txFloatData.empty()) {
        memcpy(txPacket + packetIndex, txFloatData.data(), txFloatData_length);
        packetIndex += txFloatData_length;
      }

      if (!txByteData.empty()) {
        memcpy(txPacket + packetIndex, txByteData.data(), txByteData_length);
        packetIndex += txByteData_length;
      }

      uint16_t txCrc = CRC.getCrc16(txPacket, txPacket_length - crc_length);
      txPacket[packetIndex++] = lowByte(txCrc);
      txPacket[packetIndex++] = highByte(txCrc);

      Serial.write(txPacket, txPacket_length);

      if (tx_errorStatus != 0b00000000) {
        digitalWrite(13, LOW);  // light on
      } else {
        digitalWrite(13, HIGH);  //light on
      }
    }
  }
}

bool checkHeader(const uint8_t header[], const size_t length, uint8_t packet[]) {
  for (int i = 0; i < length; i++) {
    if (Serial.read() != header[i]) {
      return false;
    }
    packet[i] = header[i];
  }
  return true;
}

void processCommand(uint8_t command, uint8_t* error) {

  float _GyroBias[3] = {};

  switch (command) {
    case estimatedAccelGyroTempCommand:
      /**
            * @brief: read the latest data from ICM42688
            * @return: latest 3-axis acceleration [g's], 3-axis gyro [bps], temperature [celsius]
            */
      if (imuBeginStatus < 0) {
        *error |= imuConnection_errorStatus;
        break;
      }

      imuResponseStatus = IMU.getAGT();

      txFloatData.push_back(IMU.accX());
      txFloatData.push_back(IMU.accY());
      txFloatData.push_back(IMU.accZ());
      txFloatData.push_back(IMU.gyrX());
      txFloatData.push_back(IMU.gyrY());
      txFloatData.push_back(IMU.gyrZ());
      txFloatData.push_back(IMU.temp());
      break;

    case estimatedAccelCommand:
      /**
            * @brief: read the latest data from ICM42688
            * @return: latest 3-axis acceleration [g's]
            */
      if (imuBeginStatus < 0) {
        *error |= imuConnection_errorStatus;
        break;
      }

      IMU.getAGT();

      txFloatData.push_back(IMU.accX());
      txFloatData.push_back(IMU.accY());
      txFloatData.push_back(IMU.accZ());
      break;

    case estimatedGyroCommand:
      /**
            * @brief: read the latest data from ICM42688
            * @return: latest 3-axis gyro [bps]
            */
      if (imuBeginStatus < 0) {
        *error |= imuConnection_errorStatus;
        break;
      }

      imuResponseStatus = IMU.getAGT();

      txFloatData.push_back(IMU.gyrX());
      txFloatData.push_back(IMU.gyrY());
      txFloatData.push_back(IMU.gyrZ());
      break;

    case estimatedTempCommand:
      /**
            * @brief: read the latest data from ICM42688
            * @return: latest temperature [celsius]
            */
      if (imuBeginStatus < 0) {
        *error |= imuConnection_errorStatus;
        break;
      }

      imuResponseStatus = IMU.getAGT();

      txFloatData.push_back(IMU.temp());
      break;

    case estimatedBiasCommand:
      /**
            * @brief: estimates the gyro bias
            * @return: estimated 3-axis gyro bias [dps]
            */
      if (imuBeginStatus < 0) {
        *error |= imuConnection_errorStatus;
        break;
      }

      _GyroBias[0] = IMU.getGyroBiasX();
      _GyroBias[1] = IMU.getGyroBiasY();
      _GyroBias[2] = IMU.getGyroBiasZ();

      imuResponseStatus = IMU.calibrateGyro();

      txFloatData.push_back(IMU.getGyroBiasX());
      txFloatData.push_back(IMU.getGyroBiasY());
      txFloatData.push_back(IMU.getGyroBiasZ());

      //! restores the bias stored in non-volatile flash memory
      //! due to the estimated bias being adapted
      IMU.setGyroBiasX(_GyroBias[0]);
      IMU.setGyroBiasY(_GyroBias[1]);
      IMU.setGyroBiasZ(_GyroBias[2]);
      break;

    case storedBiasCommand:
      /**
            * @brief: reads gyro bias stored in non-volatile flash memory
            * @return: 3-axis gyro bias [dps] in non-volatile flash memory
            */

      txFloatData.push_back(gyrB_x.read());
      txFloatData.push_back(gyrB_y.read());
      txFloatData.push_back(gyrB_z.read());
      break;

    case adaptedBiasCommand:
      /**
            * @brief: reads adapted gyro bias
            * @return: adapted 3-axis gyro bias [dps]
            */

      txFloatData.push_back(IMU.getGyroBiasX());
      txFloatData.push_back(IMU.getGyroBiasY());
      txFloatData.push_back(IMU.getGyroBiasZ());
      break;

    case setupBiasCommand:
      /**
            * @brief: estimates the gyro bias, adapt the estimated gyro bias, store it in non-volatile flash memory
            * @return: estimated 3-axis gyro bias [dps]
            */
      if (imuBeginStatus < 0) {
        *error |= imuConnection_errorStatus;
        break;
      }

      imuResponseStatus = IMU.calibrateGyro();

      //! store bias in non-volatile flash memory
      gyrB_x.write(IMU.getGyroBiasX());
      gyrB_y.write(IMU.getGyroBiasY());
      gyrB_z.write(IMU.getGyroBiasZ());

      txFloatData.push_back(IMU.getGyroBiasX());
      txFloatData.push_back(IMU.getGyroBiasY());
      txFloatData.push_back(IMU.getGyroBiasZ());
      break;

    case replaceSpecifiedBiasCommand:
      /**
            * @brief: adapt the specified gyro bias and store it in non-volatile flash memory
            * @return: 3-axis gyro bias [dps] after adaptation
            */

      if (rxFloatData.empty() || rxFloatData.size() != 3) {
        *error |= commandProcessing_errorStatus;
        break;
      }

      IMU.setGyroBiasX(rxFloatData.at(0));
      IMU.setGyroBiasY(rxFloatData.at(1));
      IMU.setGyroBiasZ(rxFloatData.at(2));

      //! store bias in non-volatile flash memory
      gyrB_x.write(rxFloatData.at(0));
      gyrB_y.write(rxFloatData.at(1));
      gyrB_z.write(rxFloatData.at(2));

      txFloatData.push_back(IMU.getGyroBiasX());
      txFloatData.push_back(IMU.getGyroBiasY());
      txFloatData.push_back(IMU.getGyroBiasZ());
      break;

    case adaptedSpecifiedBiasCommand:
      /**
            * @brief: adapt the specified gyro bias
            * @return: 3-axis gyro bias [dps] after adaptation
            */

      if (rxFloatData.empty() || rxFloatData.size() != 3) {
        *error |= commandProcessing_errorStatus;
        break;
      }

      IMU.setGyroBiasX(rxFloatData.at(0));
      IMU.setGyroBiasY(rxFloatData.at(1));
      IMU.setGyroBiasZ(rxFloatData.at(2));

      txFloatData.push_back(IMU.getGyroBiasX());
      txFloatData.push_back(IMU.getGyroBiasY());
      txFloatData.push_back(IMU.getGyroBiasZ());
      break;

    case cheackFirmwareCommand:
      /**
            * @brief:
            * @return: firmware virsion
            */

      txByteData.push_back(firmwareVersion);
      break;

    default:
      *error |= commandUnsupport_errorStatus;
  }

  if (imuResponseStatus < 0) {
    *error |= imuResponse_errorStatus;
  }
}

void initializeSerial(uint32_t baudrate) {
  Serial.begin(baudrate);
  while (!Serial) {
    ;  // wait for serial port to connect. Needed for native USB
  }
}

void initializeIMU() {
  imuBeginStatus = IMU.begin();

  IMU.setGyroBiasX(gyrB_x.read());
  IMU.setGyroBiasY(gyrB_y.read());
  IMU.setGyroBiasZ(gyrB_z.read());
}

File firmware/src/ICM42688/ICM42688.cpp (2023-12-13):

/*
  Copyright (c) 2023 Masato Kubotera

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
  This library is based on the Arduino library for communicating with the ICM42688: "https://github.com/finani/ICM42688" written by Inhwan Wee, with parameters modified for use with the SUSTAINA-OP.


  Copyright (c) 2022 Inhwan Wee

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
  THE SOFTWARE IS PROVIDED "AS IS", WITHOUT WARRANTY OF ANY KIND, EXPRESS OR
  IMPLIED, INCLUDING BUT NOT LIMITED TO THE WARRANTIES OF MERCHANTABILITY,
  FITNESS FOR A PARTICULAR PURPOSE AND NONINFRINGEMENT. IN NO EVENT SHALL THE
  AUTHORS OR COPYRIGHT HOLDERS BE LIABLE FOR ANY CLAIM, DAMAGES OR OTHER
  LIABILITY, WHETHER IN AN ACTION OF CONTRACT, TORT OR OTHERWISE, ARISING FROM,
  OUT OF OR IN CONNECTION WITH THE SOFTWARE OR THE USE OR OTHER DEALINGS IN THE
  SOFTWARE.
*/

#include "Arduino.h"
#include "ICM42688.h"
#include "registers.h"

using namespace ICM42688reg;

/* ICM42688 object, input the I2C bus and address */
ICM42688::ICM42688(TwoWire &bus, uint8_t address) {
  _i2c = &bus; // I2C bus
  _address = address; // I2C address
  _useSPI = false; // set to use I2C
}

/* ICM42688 object, input the SPI bus and chip select pin */
ICM42688::ICM42688(SPIClass &bus, uint8_t csPin, uint32_t SPI_HS_CLK) {
  _spi = &bus; // SPI bus
  _csPin = csPin; // chip select pin
  _useSPI = true; // set to use SPI
  SPI_HS_CLOCK = SPI_HS_CLK;
}

/* starts communication with the ICM42688 */
int ICM42688::begin() {
  if( _useSPI ) { // using SPI for communication
    // use low speed SPI for register setting
    _useSPIHS = false;
    // setting CS pin to output
    pinMode(_csPin,OUTPUT);
    // setting CS pin high
    digitalWrite(_csPin,HIGH);
    // begin SPI communication
    _spi->begin();
  } else { // using I2C for communication
    // starting the I2C bus
    _i2c->begin();
    // setting the I2C clock
    _i2c->setClock(I2C_CLK);
  }

  // reset the ICM42688
  reset();

  // check the WHO AM I byte
  if(whoAmI() != WHO_AM_I) {
    return -3;
  }

  // turn on accel and gyro in Low Noise (LN) Mode
  if(writeRegister(UB0_REG_PWR_MGMT0, 0x0F) < 0) {
    return -4;
  }
  delay(100);

  // 16G is default -- do this to set up accel resolution scaling
  // int ret = setAccelFS(gpm16);
  // 8G is custom - do this to set up accel resolution scaling
  int ret = setAccelFS(gpm8);
  if (ret < 0) return ret;

  // 2000DPS is default -- do this to set up gyro resolution scaling
  // ret = setGyroFS(dps2000);
  // 1000DPS is custom -- do this to set up gyro resolution scaling
  ret = setGyroFS(dps1000);
  if (ret < 0) return ret;

  // custom - low speed SPI for register setting
  ret = setAccelODR(odr200);
  if (ret < 0) return ret;

  // custom - low speed SPI for register setting
  ret = setGyroODR(odr200);
  if (ret < 0) return ret;

  // // disable inner filters (Notch filter, Anti-alias filter, UI filter block)
  // if (setFilters(false, false) < 0) {
  //   return -7;
  // }

  // estimate gyro bias
  /*
    if (calibrateGyro() < 0) {
      return -8;
    }
  */
  // successful init, return 1
  return 1;
}

/* sets the accelerometer full scale range to values other than default */
int ICM42688::setAccelFS(AccelFS fssel) {
  // use low speed SPI for register setting
  _useSPIHS = false;

  setBank(0);

  // read current register value
  uint8_t reg;
  if (readRegisters(UB0_REG_ACCEL_CONFIG0, 1, &reg) < 0) return -1;

  // only change FS_SEL in reg
  reg = (fssel << 5) | (reg & 0x1F);

  if (writeRegister(UB0_REG_ACCEL_CONFIG0, reg) < 0) return -2;

  _accelScale = static_cast<float>(1 << (4 - fssel)) / 32768.0f;
  _accelFS = fssel;

  return 1;
}

/* sets the gyro full scale range to values other than default */
int ICM42688::setGyroFS(GyroFS fssel) {
  // use low speed SPI for register setting
  _useSPIHS = false;

  setBank(0);

  // read current register value
  uint8_t reg;
  if (readRegisters(UB0_REG_GYRO_CONFIG0, 1, &reg) < 0) return -1;

  // only change FS_SEL in reg
  reg = (fssel << 5) | (reg & 0x1F);

  if (writeRegister(UB0_REG_GYRO_CONFIG0, reg) < 0) return -2;

  _gyroScale = (2000.0f / static_cast<float>(1 << fssel)) / 32768.0f;
  _gyroFS = fssel;

  return 1;
}

int ICM42688::setAccelODR(ODR odr) {
  // use low speed SPI for register setting
  _useSPIHS = false;

  setBank(0);

  // read current register value
  uint8_t reg;
  if (readRegisters(UB0_REG_ACCEL_CONFIG0, 1, &reg) < 0) return -1;

  // only change ODR in reg
  reg = odr | (reg & 0xF0);

  if (writeRegister(UB0_REG_ACCEL_CONFIG0, reg) < 0) return -2;

  return 1;
}

int ICM42688::setGyroODR(ODR odr) {
  // use low speed SPI for register setting
  _useSPIHS = false;

  setBank(0);

  // read current register value
  uint8_t reg;
  if (readRegisters(UB0_REG_GYRO_CONFIG0, 1, &reg) < 0) return -1;

  // only change ODR in reg
  reg = odr | (reg & 0xF0);

  if (writeRegister(UB0_REG_GYRO_CONFIG0, reg) < 0) return -2;

  return 1;
}

int ICM42688::setFilters(bool gyroFilters, bool accFilters) {
  if (setBank(1) < 0) return -1;

  if (gyroFilters == true) {
    if (writeRegister(UB1_REG_GYRO_CONFIG_STATIC2, GYRO_NF_ENABLE | GYRO_AAF_ENABLE) < 0) {
      return -2;
    }
  }
  else {
    if (writeRegister(UB1_REG_GYRO_CONFIG_STATIC2, GYRO_NF_DISABLE | GYRO_AAF_DISABLE) < 0) {
      return -3;
    }
  }
  
  if (setBank(2) < 0) return -4;

  if (accFilters == true) {
    if (writeRegister(UB2_REG_ACCEL_CONFIG_STATIC2, ACCEL_AAF_ENABLE) < 0) {
      return -5;
    }
  }
  else {
    if (writeRegister(UB2_REG_ACCEL_CONFIG_STATIC2, ACCEL_AAF_DISABLE) < 0) {
      return -6;
    }
  }
  if (setBank(0) < 0) return -7;
  return 1;
}

int ICM42688::enableDataReadyInterrupt() {
  // use low speed SPI for register setting
  _useSPIHS = false;

  // push-pull, pulsed, active HIGH interrupts
  if (writeRegister(UB0_REG_INT_CONFIG, 0x18 | 0x03) < 0) return -1;

  // need to clear bit 4 to allow proper INT1 and INT2 operation
  uint8_t reg;
  if (readRegisters(UB0_REG_INT_CONFIG1, 1, &reg) < 0) return -2;
  reg &= ~0x10;
  if (writeRegister(UB0_REG_INT_CONFIG1, reg) < 0) return -3;

  // route UI data ready interrupt to INT1
  if (writeRegister(UB0_REG_INT_SOURCE0, 0x18) < 0) return -4;

  return 1;
}

int ICM42688::disableDataReadyInterrupt() {
  // use low speed SPI for register setting
  _useSPIHS = false;

  // set pin 4 to return to reset value
  uint8_t reg;
  if (readRegisters(UB0_REG_INT_CONFIG1, 1, &reg) < 0) return -1;
  reg |= 0x10;
  if (writeRegister(UB0_REG_INT_CONFIG1, reg) < 0) return -2;

  // return reg to reset value
  if (writeRegister(UB0_REG_INT_SOURCE0, 0x10) < 0) return -3;

  return 1;
}
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

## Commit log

2023-06-29 Update pins of CS for SPI communication
2023-07-04 Allowed the master cpu to perform the reset
    [firmware.ino]
2023-07-04 upload EAGLE files
    [IMU-Measurement-and-Transmission-Module.brd, IMU-Measurement-and-Transmission-Module.sch]
2023-07-07 Changed the method of acquiring gyro bias to a method other than at the start
2023-07-08 Eliminate computerized resets from the master
    [firmware.ino]
2023-09-02 Added temperature (in degrees Celsius) to the measured value
2023-09-03 Added bias value and temperature acquisition by sending the letter T or t
2023-11-08 added sample code for the master-slave side
2023-11-12 Eliminated the reset command due to the fact that reconnecting the port resets it.
    [firmware.ino]
2023-11-12 Supports error detection related to IMU status
    [ICM42688.cpp, ICM42688.h, firmware.ino]
2023-11-19 Addressed the problem that error handling related to WhoAmI takes one extra loop.
    [firmware.ino]
2023-11-19 Changed the LED to light up when an error occurs.
    [firmware.ino]

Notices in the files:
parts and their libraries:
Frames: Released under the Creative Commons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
